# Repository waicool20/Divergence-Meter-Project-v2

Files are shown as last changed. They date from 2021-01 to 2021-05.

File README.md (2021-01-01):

# Divergence Meter Project v2

This is the second iteration of the [Divergence Meter Project](https://github.com/waicool20/Divergence-Meter-Project) and another personal learning project, this time learning how to integrate Li-Ion batteries into a project, new electrical converter topologies, Rust Programming Language and IoT.

Hardware is mostly finalized and most of the work left to do is actually programming the thing to work like the first program along with IoT capabilities via Android companion app. README will remain brief until I actually finish working on this, stay tuned :)

# Images

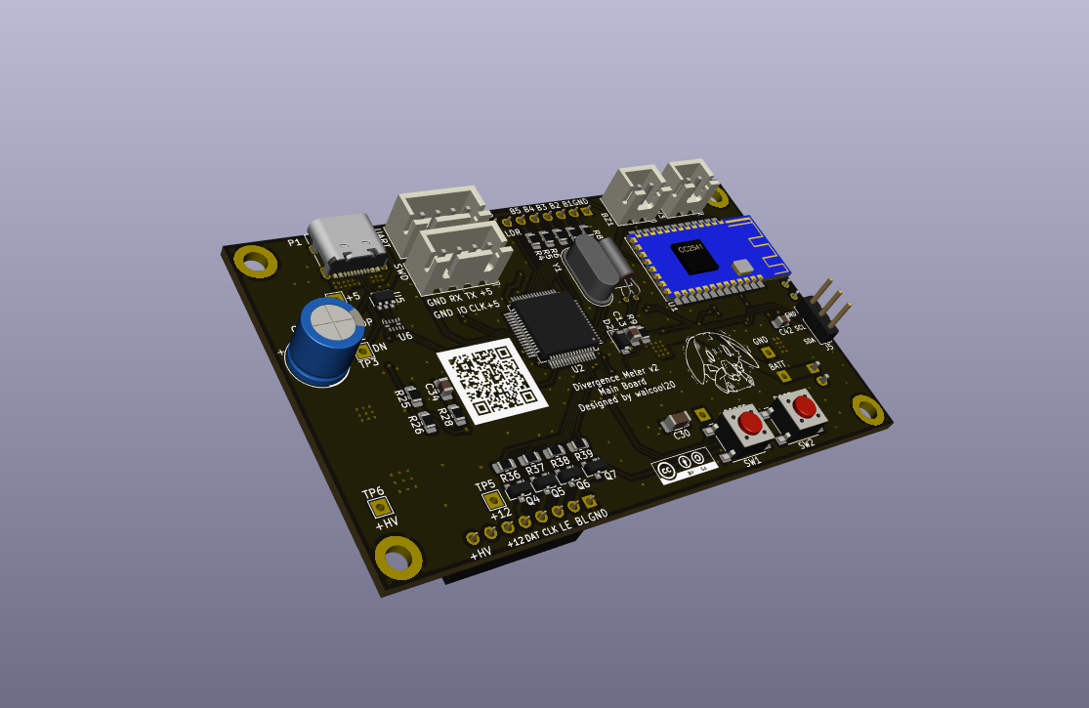
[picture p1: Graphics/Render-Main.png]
Main Board


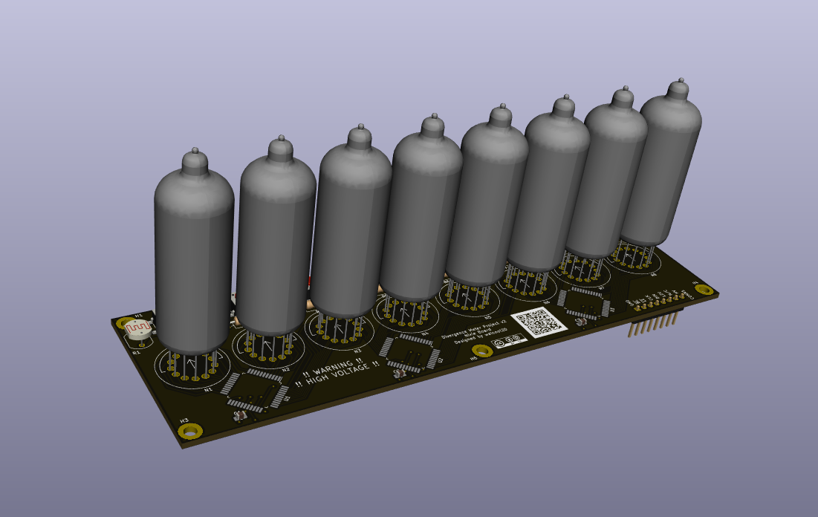
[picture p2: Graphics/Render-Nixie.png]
Nixie Board




# Licenses

Hardware: [Creative Commons Attribution-ShareAlike 4.0 International](https://creativecommons.org/licenses/by-sa/4.0/)  
Software: [GPLv3](https://www.gnu.org/licenses/gpl-3.0.txt)

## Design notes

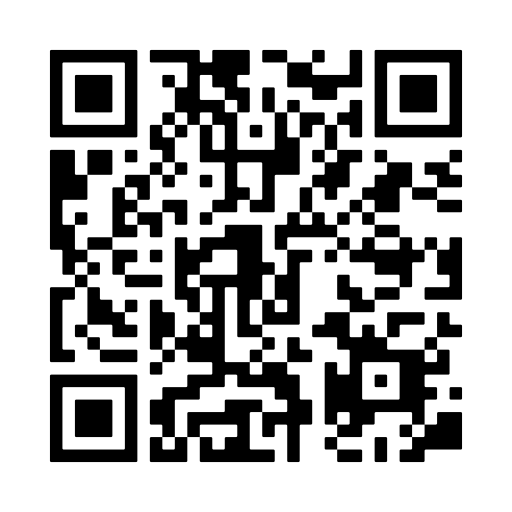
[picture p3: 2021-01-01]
Graphics/GitHub-Link-QR.png

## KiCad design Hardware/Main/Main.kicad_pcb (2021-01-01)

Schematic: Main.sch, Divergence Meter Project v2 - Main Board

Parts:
BZ1: Buzzer; JST_XH_B2B-XH-A_1x02_P2.50mm_Vertical
C1, C2, C3, C4, C5, C6, C7, C8, C13, C14, C15, C16, C17: 0.1u; C_0805_2012Metric_Pad1.18x1.45mm_HandSolder
C9, C10: 22p; C_0805_2012Metric_Pad1.18x1.45mm_HandSolder
C11, C12: 6pf; C_0805_2012Metric_Pad1.18x1.45mm_HandSolder
C43: 2.2u; C_0805_2012Metric_Pad1.18x1.45mm_HandSolder
D1: LL4148; D_MiniMELF
D2: MMSZ4684 3.3v; D_SOD-123
H1, H2, H3, H4: MountingHole_Pad; MountingHole_3.2mm_M3_ISO7380_Pad
J1: SWD; JST_XH_B4B-XH-A_1x04_P2.50mm_Vertical
J2: UART; JST_XH_B4B-XH-A_1x04_P2.50mm_Vertical
J3: CONN1; PinSocket_1x08_P2.54mm_Vertical
J4: CONN2; PinSocket_1x08_P2.54mm_Vertical
Q1: Si2300; SOT-23
R1: 1k; R_0805_2012Metric_Pad1.20x1.40mm_HandSolder
R2, R3, R4, R5, R6, R7, R8, R9, R47: 10k; R_0805_2012Metric_Pad1.20x1.40mm_HandSolder
SW1: Reset; SW_SPST_PTS645
SW2: Boot; SW_SPST_PTS645
U1: DX-BT24
U2: STM32F401RCTx; LQFP-64_10x10mm_P0.5mm
Y1: 8MHz; Crystal_HC49-4H_Vertical
Y2: 32.768kHz; Crystal_C38-LF_D3.0mm_L8.0mm_Horizontal

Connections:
+3V0: C6.2, C14.1, C15.1, C16.1, C17.1, J4.8, R2.1, SW2.2, U1.12, U2.13 (VREF+), U2.19 (VDD), U2.32 (VDD), U2.48 (VDD), U2.64 (VDD); also elsewhere on the board
+5V: J1.1, J2.1; also elsewhere on the board
+12V: J3.6; also elsewhere on the board
+BATT: R9.2; also elsewhere on the board
+HV: J3.8; also elsewhere on the board
/Level Shifter/OUT1: J3.5; also elsewhere on the board
/Level Shifter/OUT2: J3.4; also elsewhere on the board
/Level Shifter/OUT3: J3.3; also elsewhere on the board
/Level Shifter/OUT4: J3.2; also elsewhere on the board
AUX_RX: J2.3, U2.43 (PA10)
AUX_TX: J2.2, U2.42 (PA9)
BATT_INT: U2.2 (PC13); also elsewhere on the board
BATT_SCL: U2.61 (PB8); also elsewhere on the board
BATT_SDA: U2.62 (PB9); also elsewhere on the board
BL: U2.59 (PB7); also elsewhere on the board
BT_CONN: U1.17, U2.15 (PA1)
BT_RX: U1.1, U2.17 (PA3)
BT_TX: U1.2, U2.16 (PA2)
BUTTON1: C3.1, R8.1, U2.21 (PA5)
BUTTON2: C4.1, R7.1, U2.22 (PA6)
BUTTON3: C5.1, R6.1, U2.23 (PA7)
BUTTON4: C7.1, R5.1, U2.24 (PC4)
BUTTON5: C8.1, R4.1, U2.25 (PC5)
BUZZER: Q1.1 (G), R47.1, U2.20 (PA4)
Boot: C2.1, R3.1, SW2.1, U2.60 (BOOT0)
CLK: U2.57 (PB5); also elsewhere on the board
DAT: U2.56 (PB4); also elsewhere on the board
GND: C1.2, C2.2, C3.2, C4.2, C5.2, C6.1, C7.2, C8.2, C9.1, C10.1, C11.1, C12.1, C13.2, C14.2, C15.2, C16.2, C17.2, C43.2, D2.2 (A), H1.1, H2.1, H3.1, H4.1, J1.4, J2.4, J3.1, J4.1, Q1.3 (D), R3.2, R47.2, SW1.1, U1.13, U1.14, U1.26, U2.12 (VSSA), U2.18 (VSS), U2.31 (VSS), U2.47 (VSS), U2.63 (VSS); also elsewhere on the board
HV_ENABLE: U2.50 (PA15); also elsewhere on the board
LDR: J4.7, U2.26 (PB0)
LE: U2.58 (PB6); also elsewhere on the board
NRST: C1.1, R2.2, SW1.2, U2.7 (NRST)
unnamed: BZ1.2 (+), D1.2 (A), Q1.2 (S)
unnamed: C9.2, U2.5 (PH0), Y1.2
unnamed: C10.2, U2.6 (PH1), Y1.1
unnamed: C11.2, U2.3 (PC14), Y2.1
unnamed: C12.2, U2.4 (PC15), Y2.2
unnamed: C13.1, D2.1 (K), R9.1, U2.1 (VBAT)
unnamed: C43.1, U2.30 (VCAP1)
unnamed: D1.1 (K), R1.2
unnamed: J4.2, R8.2
unnamed: J4.3, R7.2
unnamed: J4.4, R6.2
unnamed: J4.5, R5.2
unnamed: J4.6, R4.2
SWDCLK: J1.2, U2.49 (PA14)
SWDIO: J1.3, U2.46 (PA13)
USB_DN: U2.44 (PA11); also elsewhere on the board
USB_DP: U2.45 (PA12); also elsewhere on the board
USB_SEL: U2.41 (PA8); also elsewhere on the board
VBUS_DETECT: U2.40 (PC9); also elsewhere on the board
VCC: BZ1.1 (-), R1.1; also elsewhere on the board

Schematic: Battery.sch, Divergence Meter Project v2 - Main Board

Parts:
BT1: 18650 3.7v; JST_XH_S2B-XH-A-1_1x02_P2.50mm_Horizontal
C18, C21, C23, C26: 1u; C_0805_2012Metric_Pad1.18x1.45mm_HandSolder
C19, C22, C25, C40, C41, C42: 0.1u; C_0805_2012Metric_Pad1.18x1.45mm_HandSolder
C20, C24, C29: 10u; C_0805_2012Metric_Pad1.18x1.45mm_HandSolder
C27: 47n; C_0805_2012Metric_Pad1.18x1.45mm_HandSolder
C28: 4.7u; C_0805_2012Metric_Pad1.18x1.45mm_HandSolder
D3: LED; LED_0805_2012Metric_Pad1.15x1.40mm_HandSolder
D6: LL5819; D_MiniMELF
D7: MMSZ4684 3.3v; D_SOD-123
J5: I2C; PinHeader_1x03_P2.54mm_Vertical
JP1: CE; SolderJumper-2_P1.3mm_Open_TrianglePad1.0x1.5mm
L1: 4.7u; CD54
P1: USB_C_Plug_USB2.0; USB_C_Receptacle_XKB_U262-16XN-4BVC11
R10, R13, R17, R18, R19, R20, R23, R24: 10k; R_0805_2012Metric_Pad1.20x1.40mm_HandSolder
R11: 1.8M; R_0805_2012Metric_Pad1.20x1.40mm_HandSolder
R12: 18.2k; R_0805_2012Metric_Pad1.20x1.40mm_HandSolder
R14, R15: 5.1k; R_0805_2012Metric_Pad1.20x1.40mm_HandSolder
R16: 0.01; R_2512_6332Metric_Pad1.40x3.35mm_HandSolder
R21: 140; R_0805_2012Metric_Pad1.20x1.40mm_HandSolder
R22, R49: 1k; R_0805_2012Metric_Pad1.20x1.40mm_HandSolder
R44, R45: 100; R_0805_2012Metric_Pad1.20x1.40mm_HandSolder
R46, R48: 100k; R_0805_2012Metric_Pad1.20x1.40mm_HandSolder
SW3: PWR; JST_XH_B2B-XH-A_1x02_P2.50mm_Vertical
TH1: 103AT-2; R_Axial_DIN0204_L3.6mm_D1.6mm_P2.54mm_Vertical
TP1: TP_5V; TestPoint_THTPad_2.0x2.0mm_Drill1.0mm
TP2: DP; TestPoint_THTPad_2.0x2.0mm_Drill1.0mm
TP3: DN; TestPoint_THTPad_2.0x2.0mm_Drill1.0mm
TP4: TP_BATT; TestPoint_THTPad_2.0x2.0mm_Drill1.0mm
TP7: TP_VCC; TestPoint_THTPad_2.0x2.0mm_Drill1.0mm
U3: ME6211C30M5; SOT-23-5
U4: BQ27510-G3; Texas_S-PDSO-N12
U5: STF202-22T1G; TSOP-6_1.65x3.05mm_P0.95mm
U6: TS3USB221A; Texas_R-PUQFN-N10
U7: BQ24295; VQFN-24-1EP_4x4mm_P0.5mm_EP2.45x2.45mm_ThermalVias

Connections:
+3V0: C21.1, R10.1, R13.1, R19.2, U3.5, U5.1, U6.10 (VCC); also elsewhere on the board
+5V: C19.2, C20.2, C26.1, D6.2 (A), P1.A4 (VBUS), P1.A9 (VBUS), P1.B4 (VBUS), P1.B9 (VBUS), R46.1, TP1.1, U7.1 (VBUS), U7.24 (VBUS); also elsewhere on the board
+BATT: BT1.1 (+), C23.1, C24.2, TP4.1, U4.3 (REGIN), U4.4 (BAT), U7.13 (BAT), U7.14 (BAT); also elsewhere on the board
BATT_GPOUT: JP1.1 (A), R18.2, U4.12 (GPOUT), U7.9 (~CE)
BATT_INT: R19.1, U7.7 (INT); also elsewhere on the board
BATT_SCL: J5.2, R10.2, U4.11 (SCL), U7.5 (SCL); also elsewhere on the board
BATT_SDA: J5.3, R13.2, U4.10 (SDA), U7.6 (SDA); also elsewhere on the board
CHARGE_DN: U6.2 (1D-), U7.3 (D-)
CHARGE_DP: U6.1 (1D+), U7.2 (D+)
GND: C18.2, C19.1, C20.1, C21.2, C22.2, C23.2, C24.1, C25.2, C26.2, C28.2, C29.1, C40.2, C41.2, D7.2 (A), J5.1, JP1.2 (B), P1.A1 (GND), P1.A12 (GND), P1.B1 (GND), P1.B12 (GND), P1.S1 (SHIELD), R14.2, R15.2, R16.2, R17.1, R20.1, R21.1, R24.2, R45.1, R48.1, TH1.2, U3.2, U4.6 (VSS), U4.13 (PAD), U5.6, U6.5 (GND), U6.6 (~OE), U7.17 (PGND), U7.18 (PGND), U7.25 (PAD); also elsewhere on the board
unnamed: BT1.2 (-), R16.1, R44.1
unnamed: C18.1, R11.1, U4.2 (REG25), U4.5 (VCC)
unnamed: C22.1, R11.2, R12.1, U4.1 (BI/TOUT)
unnamed: C25.1, R49.1, U4.9 (TS)
unnamed: C27.1, U7.21 (BTST)
unnamed: C27.2, L1.1, U7.19 (SW), U7.20 (SW)
unnamed: C28.1, R23.1, U7.22 (REGN)
unnamed: C40.1, C42.2, R45.2, U4.8 (SRN)
unnamed: C41.1, C42.1, R44.2, U4.7 (SRP)
unnamed: D3.1 (K), R22.1
unnamed: D6.1 (K), U3.1, U3.3
unnamed: P1.A5 (CC1), R15.1
unnamed: P1.A6 (D+), P1.B6 (D+), TP2.1, U5.3
unnamed: P1.A7 (D-), P1.B7 (D-), TP3.1, U5.2
unnamed: P1.B5 (CC2), R14.1
unnamed: R12.2, R49.2, TH1.1
unnamed: R20.2, U7.8 (OTG)
unnamed: R21.2, U7.10 (ILIM)
unnamed: R22.2, U7.4 (STAT)
unnamed: R23.2, R24.1, U7.11 (TS)
unnamed: U5.4, U6.8 (D+)
unnamed: U5.5, U6.7 (D-)
USB_DN: U6.4 (2D-); also elsewhere on the board
USB_DP: U6.3 (2D+); also elsewhere on the board
USB_SEL: R17.2, U6.9 (S); also elsewhere on the board
VBUS_DETECT: D7.1 (K), R46.2, R48.2; also elsewhere on the board
VCC: SW3.2 (B), TP7.1; also elsewhere on the board
VSYS: C29.2, D3.2 (A), L1.2, R18.1, SW3.1 (A), U7.15 (SYS), U7.16 (SYS)

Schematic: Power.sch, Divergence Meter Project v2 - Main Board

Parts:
C30, C32, C33: 22u; C_1206_3216Metric_Pad1.33x1.80mm_HandSolder
C31, C34, C37: 0.1u; C_0805_2012Metric_Pad1.18x1.45mm_HandSolder
C35: 470u; CP_Radial_D8.0mm_P3.50mm
C36, C39: 1u; C_0805_2012Metric_Pad1.18x1.45mm_HandSolder
C38: 2.2u 250v; C_1210_3225Metric_Pad1.33x2.70mm_HandSolder
D4: SS34; D_SMA-SMB_Universal_Handsoldering
D5: MURS240; D_SMB_Handsoldering
L2: 4.7u; CD54
Q2: Si2300; SOT-23
Q3: SUD70090E-GE3; TO-252-2
R25, R26, R29, R30: 100k; R_0805_2012Metric_Pad1.20x1.40mm_HandSolder
R27, R32: 10k; R_0805_2012Metric_Pad1.20x1.40mm_HandSolder
R28: 4.7k; R_0805_2012Metric_Pad1.20x1.40mm_HandSolder
R31: 200k; R_0805_2012Metric_Pad1.20x1.40mm_HandSolder
R33: 0.01; R_2512_6332Metric_Pad1.40x3.35mm_HandSolder
R34: 15k; R_0805_2012Metric_Pad1.20x1.40mm_HandSolder
R35: 2M; R_0805_2012Metric_Pad1.20x1.40mm_HandSolder
T1: TTRN-0530H
TP5: TP_12V; TestPoint_THTPad_2.0x2.0mm_Drill1.0mm
TP6: TP_HV; TestPoint_THTPad_2.0x2.0mm_Drill1.0mm
TP8: TP_GND; TestPoint_THTPad_2.0x2.0mm_Drill1.0mm
U8: LM3481; VSSOP-10_3x3mm_P0.5mm
U9: SX1308; TSOT-23-6
U10: ME6211C30M5; SOT-23-5

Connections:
+3V0: C39.1, U10.5; also elsewhere on the board
+12V: C33.1, D4.1 (K), R31.1, TP5.1; also elsewhere on the board
+HV: C38.1, D5.1 (K), R35.1, TP6.1; also elsewhere on the board
GND: C30.2, C31.2, C32.2, C33.2, C34.2, C35.2, C36.2, C37.2, C38.2, C39.2, Q2.2 (S), R25.2, R27.2, R32.2, R33.2, R34.2, T1.5, TP8.1, U8.5 (AGND), U8.7 (PGND), U9.2, U10.2; also elsewhere on the board
HV_ENABLE: Q2.1 (G), R27.1; also elsewhere on the board
unnamed: C31.1, U8.9 (VCC)
unnamed: C34.1, R28.1
unnamed: C37.1, Q3.3 (S), R33.1, U8.1 (Isen)
unnamed: D4.2 (A), L2.2, U9.1
unnamed: D5.2 (A), T1.3
unnamed: Q2.3 (D), R29.2, R30.1
unnamed: Q3.1 (G), U8.8 (DR)
unnamed: Q3.2 (D), T1.1
unnamed: R25.1, R26.2, U8.2 (UVLO)
unnamed: R28.2, U8.3 (COMP)
unnamed: R29.1, U8.6 (FA/SYNC/SD)
unnamed: R31.2, R32.1, U9.3
unnamed: R34.1, R35.2, U8.4 (FB)
VCC: C30.1, C32.1, C35.1, C36.1, L2.1, R26.1, R30.2, T1.2, U8.10 (Vin), U9.4, U9.5, U10.1, U10.3; also elsewhere on the board

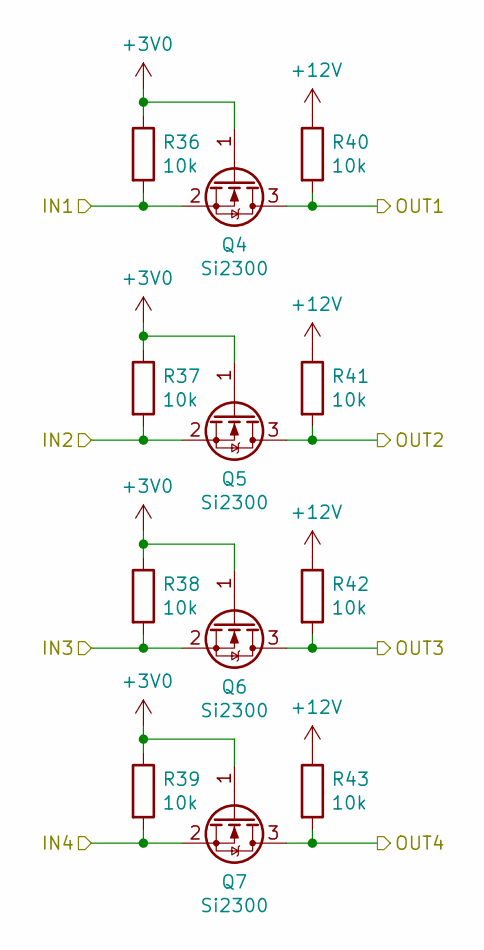
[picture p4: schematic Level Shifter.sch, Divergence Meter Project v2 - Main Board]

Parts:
Q4, Q5, Q6, Q7: Si2300; SOT-23
R36, R37, R38, R39, R40, R41, R42, R43: 10k; R_0805_2012Metric_Pad1.20x1.40mm_HandSolder

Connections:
+3V0: Q4.1 (G), Q5.1 (G), Q6.1 (G), Q7.1 (G), R36.1, R37.1, R38.1, R39.1; also elsewhere on the board
+12V: R40.1, R41.1, R42.1, R43.1; also elsewhere on the board
/Level Shifter/OUT1: Q4.3 (D), R40.2; also elsewhere on the board
/Level Shifter/OUT2: Q5.3 (D), R41.2; also elsewhere on the board
/Level Shifter/OUT3: Q6.3 (D), R42.2; also elsewhere on the board
/Level Shifter/OUT4: Q7.3 (D), R43.2; also elsewhere on the board
BL: Q7.2 (S), R39.2; also elsewhere on the board
CLK: Q5.2 (S), R37.2; also elsewhere on the board
DAT: Q4.2 (S), R36.2; also elsewhere on the board
LE: Q6.2 (S), R38.2; also elsewhere on the board

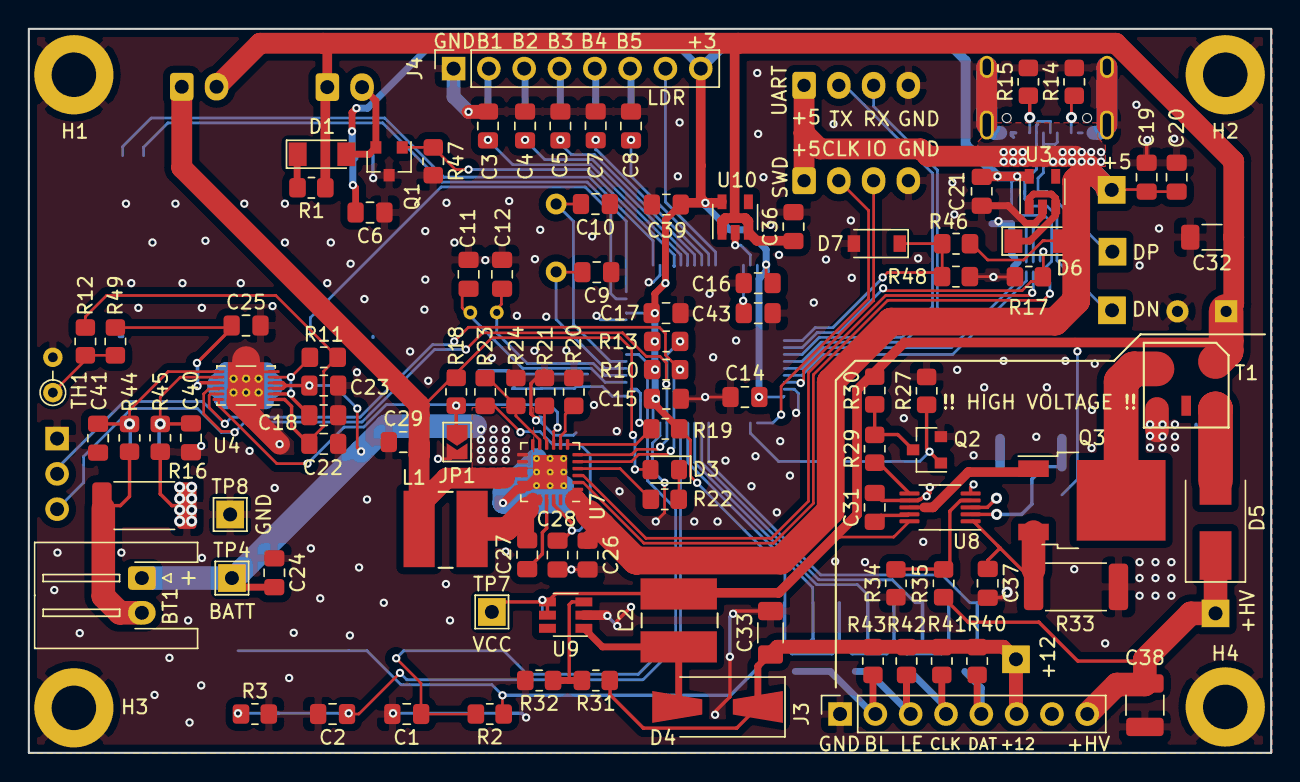
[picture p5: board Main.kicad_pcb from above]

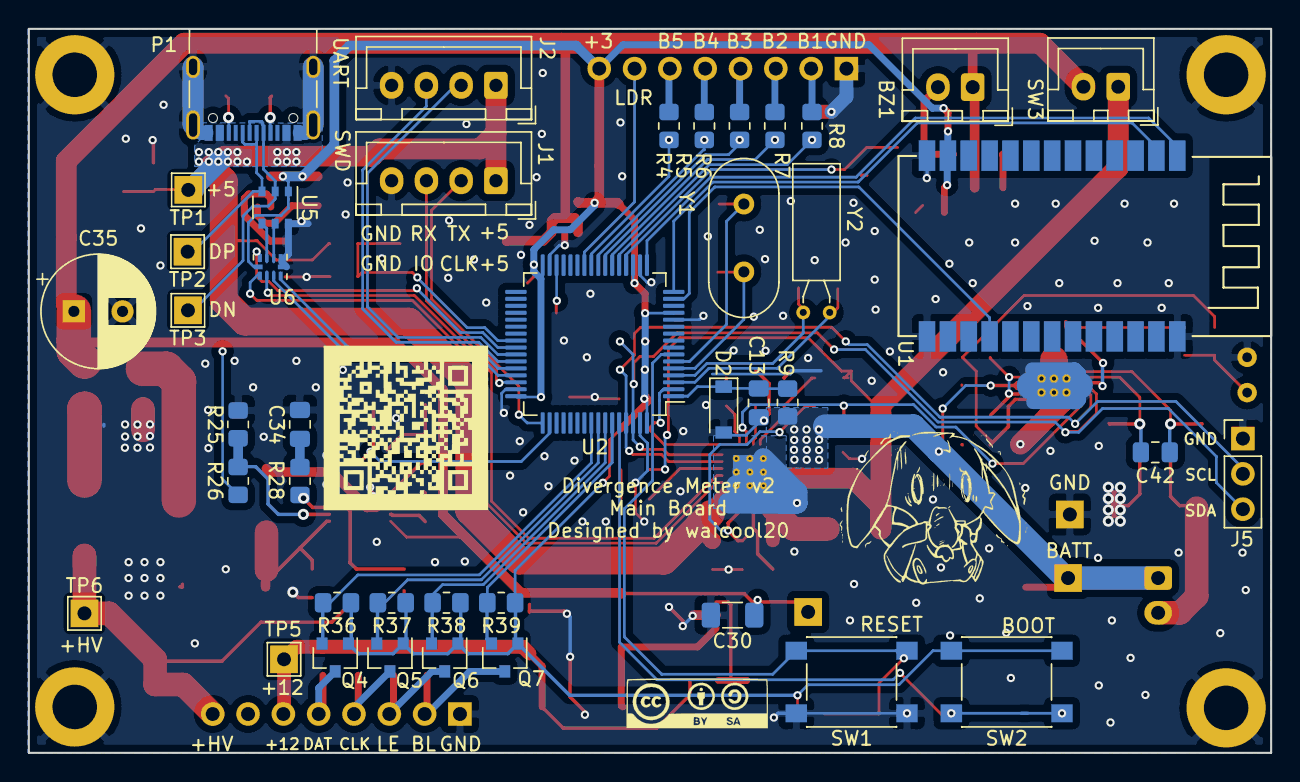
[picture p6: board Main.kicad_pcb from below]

Board: 2 copper layers, 89.3 x 52.1 mm, 146 parts (42 on the bottom side), 91 nets.

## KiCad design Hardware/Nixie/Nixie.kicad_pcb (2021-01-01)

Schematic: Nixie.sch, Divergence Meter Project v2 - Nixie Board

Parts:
C1, C2, C3: 0.1u; C_0805_2012Metric_Pad1.15x1.40mm_HandSolder
H1, H2, H3, H4, H5, H6: MountingHole_Pad; MountingHole_3.2mm_M3_ISO7380_Pad
J1: CONN1; PinHeader_1x08_P2.54mm_Vertical
J2: CONN2; PinHeader_1x08_P2.54mm_Vertical
N1, N2, N3, N4, N5, N6, N7, N8: IN-14
R1: LDR 5516 ( 5-10k ); R_LDR_7x6mm_P5.1mm_Vertical
R2: 100k; R_0805_2012Metric_Pad1.15x1.40mm_HandSolder
R3, R4, R5, R6, R7, R8, R9, R10: 22k; R_Axial_DIN0207_L6.3mm_D2.5mm_P10.16mm_Horizontal
R11, R12, R13, R14, R15: 10k; R_0805_2012Metric_Pad1.15x1.40mm_HandSolder
RV1, RV2, RV3, RV4, RV5, RV6, RV7, RV8: 50k; 3362P
SW1: BUTTON1; SW_SPST_PTS645
SW2: BUTTON2; SW_SPST_PTS645
SW3: BUTTON3; SW_SPST_PTS645
SW4: BUTTON4; SW_SPST_PTS645
SW5: BUTTON5; SW_SPST_PTS645
U1, U2, U3: HV5622-PG; MQFP-44_10x10mm_P0.8mm

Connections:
+3V0: J2.8, R1.1, SW1.2, SW2.2, SW3.2, SW4.2, SW5.2
+12V: C1.1, C2.1, C3.1, J1.6, U1.27, U1.30, U2.27, U2.30, U3.27, U3.30
+HV: J1.8, R3.1, R4.1, R5.1, R6.1, R7.1, R8.1, R9.1, R10.1
BUTTON1: J2.2, R15.1, SW1.1
BUTTON2: J2.3, R14.1, SW2.1
BUTTON3: J2.4, R13.1, SW3.1
BUTTON4: J2.5, R12.1, SW4.1
BUTTON5: J2.6, R11.1, SW5.1
GND: C1.2, C2.2, C3.2, H1.1, H2.1, H3.1, H4.1, H5.1, H6.1, J1.1, J2.1, R2.2, R11.2, R12.2, R13.2, R14.2, R15.2, U1.29, U2.29, U3.29
unnamed: J1.2, U1.33, U2.33, U3.33
unnamed: J1.3, U1.31, U2.31, U3.31
unnamed: J1.4, U1.28, U2.28, U3.28
unnamed: J1.5, U1.32
unnamed: J2.7, R1.2, R2.1
unnamed: N1.1 (A), RV1.2
unnamed: N1.2 (LDP), U1.22
unnamed: N1.3 (1), U1.21
unnamed: N1.4 (2), U1.20
unnamed: N1.5 (3), U1.19
unnamed: N1.6 (4), U1.18
unnamed: N1.7 (5), U1.17
unnamed: N1.8 (6), U1.16
unnamed: N1.9 (7), U1.15
unnamed: N1.10 (8), U1.14
unnamed: N1.11 (9), U1.13
unnamed: N1.12 (0), U1.12
unnamed: N1.13 (RDP), U1.11
unnamed: N2.1 (A), RV2.2
unnamed: N2.2 (LDP), U1.10
unnamed: N2.3 (1), U1.9
unnamed: N2.4 (2), U1.8
unnamed: N2.5 (3), U1.7
unnamed: N2.6 (4), U1.6
unnamed: N2.7 (5), U1.5
unnamed: N2.8 (6), U1.4
unnamed: N2.9 (7), U1.3
unnamed: N2.10 (8), U1.2
unnamed: N2.11 (9), U1.1
unnamed: N2.12 (0), U1.44
unnamed: N2.13 (RDP), U1.43
unnamed: N3.1 (A), RV3.2
unnamed: N3.2 (LDP), U1.42
unnamed: N3.3 (1), U1.41
unnamed: N3.4 (2), U1.40
unnamed: N3.5 (3), U1.39
unnamed: N3.6 (4), U1.38
unnamed: N3.7 (5), U1.37
unnamed: N3.8 (6), U1.36
unnamed: N3.9 (7), U1.35
unnamed: N3.10 (8), U2.22
unnamed: N3.11 (9), U2.21
unnamed: N3.12 (0), U2.20
unnamed: N3.13 (RDP), U2.19
unnamed: N4.1 (A), RV4.2
unnamed: N4.2 (LDP), U2.18
unnamed: N4.3 (1), U2.17
unnamed: N4.4 (2), U2.16
unnamed: N4.5 (3), U2.15
unnamed: N4.6 (4), U2.14
unnamed: N4.7 (5), U2.13
unnamed: N4.8 (6), U2.12
unnamed: N4.9 (7), U2.11
unnamed: N4.10 (8), U2.10
unnamed: N4.11 (9), U2.9
unnamed: N4.12 (0), U2.8
unnamed: N4.13 (RDP), U2.7
unnamed: N5.1 (A), RV5.2
unnamed: N5.2 (LDP), U2.6
unnamed: N5.3 (1), U2.5
unnamed: N5.4 (2), U2.4
unnamed: N5.5 (3), U2.3
unnamed: N5.6 (4), U2.2
unnamed: N5.7 (5), U2.1
unnamed: N5.8 (6), U2.44
unnamed: N5.9 (7), U2.43
unnamed: N5.10 (8), U2.42
unnamed: N5.11 (9), U2.41
unnamed: N5.12 (0), U2.40
unnamed: N5.13 (RDP), U2.39
unnamed: N6.1 (A), RV6.2
unnamed: N6.2 (LDP), U2.38
unnamed: N6.3 (1), U2.37
unnamed: N6.4 (2), U2.36
unnamed: N6.5 (3), U2.35
unnamed: N6.6 (4), U3.22
unnamed: N6.7 (5), U3.21
unnamed: N6.8 (6), U3.20
unnamed: N6.9 (7), U3.19
unnamed: N6.10 (8), U3.18
unnamed: N6.11 (9), U3.17
unnamed: N6.12 (0), U3.16
unnamed: N6.13 (RDP), U3.15
unnamed: N7.1 (A), RV7.2
unnamed: N7.2 (LDP), U3.14
unnamed: N7.3 (1), U3.13
unnamed: N7.4 (2), U3.12
unnamed: N7.5 (3), U3.11
unnamed: N7.6 (4), U3.10
unnamed: N7.7 (5), U3.9
unnamed: N7.8 (6), U3.8
unnamed: N7.9 (7), U3.7
unnamed: N7.10 (8), U3.6
unnamed: N7.11 (9), U3.5
unnamed: N7.12 (0), U3.4
unnamed: N7.13 (RDP), U3.3
unnamed: N8.1 (A), RV8.2
unnamed: N8.2 (LDP), U3.2
unnamed: N8.3 (1), U3.1
unnamed: N8.4 (2), U3.44
unnamed: N8.5 (3), U3.43
unnamed: N8.6 (4), U3.42
unnamed: N8.7 (5), U3.41
unnamed: N8.8 (6), U3.40
unnamed: N8.9 (7), U3.39
unnamed: N8.10 (8), U3.38
unnamed: N8.11 (9), U3.37
unnamed: N8.12 (0), U3.36
unnamed: N8.13 (RDP), U3.35
unnamed: R3.2, RV1.1
unnamed: R4.2, RV2.1
unnamed: R5.2, RV3.1
unnamed: R6.2, RV4.1
unnamed: R7.2, RV5.1
unnamed: R8.2, RV6.1
unnamed: R9.2, RV7.1
unnamed: R10.2, RV8.1
unnamed: U1.23, U2.32
unnamed: U2.23, U3.32

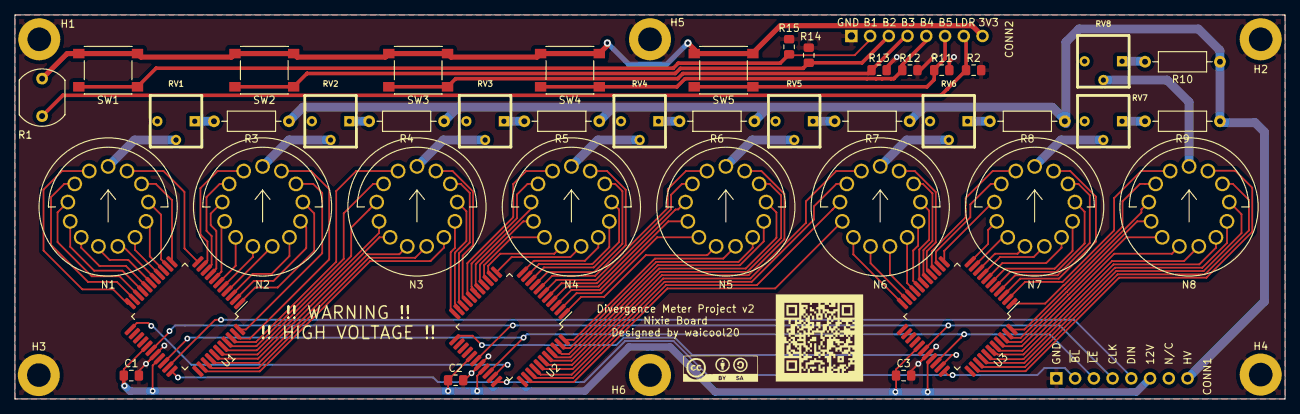
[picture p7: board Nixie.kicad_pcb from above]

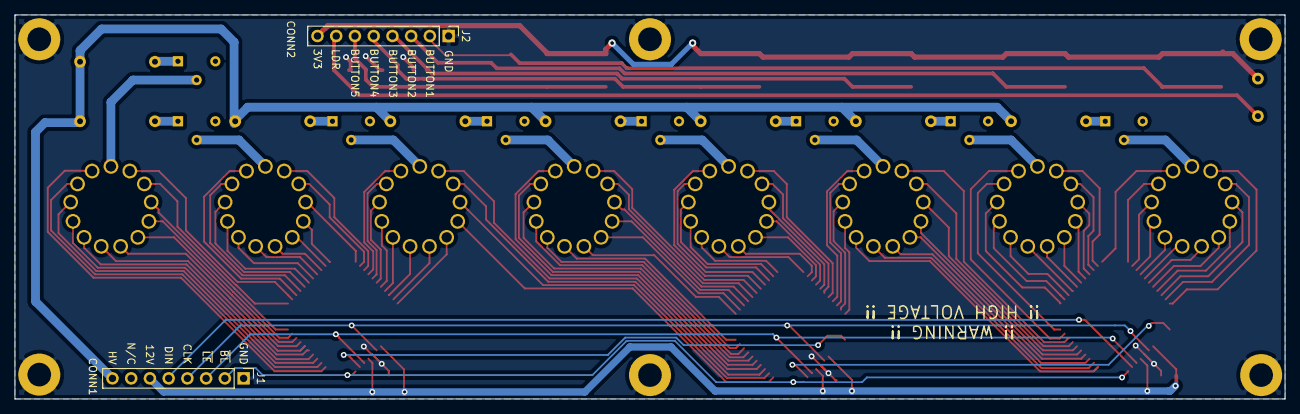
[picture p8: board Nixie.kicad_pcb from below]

Board: 2 copper layers, 172.2 x 52.1 mm, 50 parts (2 on the bottom side), 128 nets.

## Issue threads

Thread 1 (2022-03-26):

transformer

mcer12, 2022-03-26:
Hi, great project! I wanted to make one but the BOM is kinda vague. The most crucial part is the transformer, you only provide type but not what particular model (properties) is needed. Could you elaborate on that?

waicool20, 2022-03-27:
I used the TTRN-0530H-044-T, 11:1 turn ratio, [datasheets should be here](https://www.tokyocoil.com/wp-content/themes/tokyo_coil/pdf/ttrn/TTRN-0530H.pdf) Particular model (044-T part) shouldn't really matter I believe IIRC

Just a note that this project is in a incomplete state, as shown by the lack of progress on the software side of things. As it is, it only displays the current time stored in the RTC with no way to set or unset settings etc.

For now the project will remain in an indefinite hiatus for personal reasons

mcer12, 2022-03-27:
@waicool20 thank you for the reply, I was in a process of ordering components so you stopped me just in time :D I'm worried about different properties - inductance, turns ratio of different models - which I expect would need adjustments of the design which I don't have the tools to properly test. The particular model TTRN-0530H-044-T doesn't seem to be available anywhere except taobao which is too foreign for me :(
Since the project is on ice, maybe I can use the booster design alone, which is super simple and elegant by the way! I've seen this project which uses same switcher but different transformer and slightly different components:
https://www.pcbway.com/project/shareproject/LM3481_high_efficiency_transformer_glow_tube_booster_module.html
but there's very little information about it, maximum current delivery for example.

waicool20, 2022-03-27:
I've not done a lot of testing on current capabilities but it is able to power the 8 tubes at max brightness down to about [3.5V](http://3.5v/) on the [4.2V](http://4.2v/) 10000 mAh li ion cells for a whole day, I havnt figured out how to extract the remaining [0.3V](http://0.3v/) or so on the discharge curve yet tho.

The project you linked has basically the same design which I kind of expected, [TI writes good guidelines on how to use their products](https://www.ti.com/lit/an/snva761a/snva761a.pdf), the only major difference in TIs design is that they use an optocoupler to have full input-output isolation, they also have a lot of extra components to enhance the performance of the circuit, which the project you linked + the one used here mostly omitted due to size driven requirements. Max output current is mostly driven by the selected components, basically if you scale the components up (eg. battery, transformer, mosfet) you can probably increase the current output, but again due to size requirements this is not always the case.

You can get those transformers off of [AliExpress](https://m.aliexpress.com/item/4001298751715.html?gatewayAdapt=Pc2Msite) which should be more accessible, this one is a slightly different model but should work just fine, you can also modify the footprint to fit any other high turn ratio transformer that are available to you.

The specific inductance of the transformers is not as crucial as we're not really powering anything very precise, nixie tubes look elegant but they are pretty crude devices functionally, so power quality is not on the top of the priority list. I wouldn't use the boost circuit for high accuracy applications.

The transformer also heats up quite a bit due to its small size which affects its power delivery capabilities, I think a passive heatsink is needed to achieve better performance.

mcer12, 2022-03-28:
Thank you very much. I will probably merge the two of your designs together, because TTRN-060s-013-T is cheaply available on Ali as I happend to find and it should have higher maximum current so it should run colder. Thank you so much for the clarifications and hope I didn't bother too much with the dumb questions :) I'll reopen the issue in case something else comes up.

Closed 2022-03-28.

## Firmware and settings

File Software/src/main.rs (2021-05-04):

#![no_std]
#![no_main]

#![allow(unused_must_use)]
#![allow(dead_code)]

#[macro_use]
extern crate num_derive;
extern crate panic_halt;
extern crate void;

mod drivers;
mod utils;
mod tasks;
mod hardware;

#[rtic::app(device = stm32f4xx_hal::stm32, peripherals = true, dispatchers = [SDIO, OTG_FS_WKUP])]
mod app {
    use dwt_systick_monotonic::DwtSystick;
    use rtic::rtic_monotonic::Seconds;
    use stm32f4xx_hal::gpio::*;
    use stm32f4xx_hal::gpio::gpioa::*;
    use stm32f4xx_hal::gpio::gpioc::*;
    use stm32f4xx_hal::gpio::gpioc::PC5;
    use stm32f4xx_hal::i2c::I2c;
    use stm32f4xx_hal::prelude::*;
    use stm32f4xx_hal::pwm::tim4;
    use stm32f4xx_hal::rcc::Clocks;
    use stm32f4xx_hal::serial::config::Config;
    use stm32f4xx_hal::serial::Serial;
    use stm32f4xx_hal::stm32;
    use stm32f4xx_hal::stm32::RTC;

    use crate::drivers::battery_charger::*;
    use crate::drivers::battery_gauge::*;
    use crate::drivers::button::Button;
    use crate::drivers::display::*;
    use crate::hardware::*;
    use crate::tasks::*;

    #[resources]
    struct Resources {
        #[lock_free]
        display: HwDisplay,
        clocks: Clocks,
        #[lock_free]
        rtc: RTC,
        #[lock_free]
        buttons: [Button; 5],
        #[lock_free]
        pin_b1: PA5<Input<Floating>>,
        #[lock_free]
        pin_b2: PA6<Input<Floating>>,
        #[lock_free]
        pin_b3: PA7<Input<Floating>>,
        #[lock_free]
        pin_b4: PC4<Input<Floating>>,
        #[lock_free]
        pin_b5: PC5<Input<Floating>>,
        #[lock_free]
        battery_charger: HwBatteryCharger,
        #[lock_free]
        battery_gauge: HwBatteryGauge,
        #[lock_free]
        vbus_detect: PC9<Input<Floating>>,
    }

    #[monotonic(binds = SysTick, default = true)]
    type MyMono = DwtSystick<8_000_000>;

    #[init]
    fn init(cx: init::Context) -> (init::LateResources, init::Monotonics) {
        let mut cp: cortex_m::Peripherals = cx.core;
        let mut dp: stm32::Peripherals = cx.device;
        cp.DWT.enable_cycle_counter();

        // Init RTC
        dp.RCC.apb1enr.modify(|_, w| w.pwren().enabled());
        dp.PWR.cr.modify(|_, w| w.dbp().set_bit());
        if dp.RCC.bdcr.read().lserdy().is_not_ready() {
            dp.RCC.bdcr.modify(|_, w| w.lseon().on());
            while dp.RCC.bdcr.read().lserdy().is_not_ready() {}
        }
        if dp.RCC.bdcr.read().rtcen().is_disabled() {
            dp.RCC.bdcr.modify(|_, w| {
                w.rtcsel().lse();
                w.rtcen().enabled()
            });
        }

        dp.RCC.apb2enr.modify(|_, w| w.syscfgen().enabled());

        let clocks = dp.RCC.constrain().cfgr.use_hse(8.mhz())
            .sysclk(48.mhz())
            .freeze();

        let mut syscfg = &mut dp.SYSCFG.constrain();

        let mut gpiob = dp.GPIOB.split();
        let mut gpioa = dp.GPIOA.split();
        let mut gpioc = dp.GPIOC.split();

        // Init Buttons
        let pin_b1 = gpioa.pa5.into_floating_input();
        let pin_b2 = gpioa.pa6.into_floating_input();
        let pin_b3 = gpioa.pa7.into_floating_input();
        let pin_b4 = gpioc.pc4.into_floating_input();
        let pin_b5 = gpioc.pc5.into_floating_input();

        // Init Display
        let pin_le = gpiob.pb6.into_push_pull_output();
        let pin_dat = gpiob.pb4.into_push_pull_output();
        let pin_clk = gpiob.pb5.into_push_pull_output();
        let pin_en = gpioa.pa15.into_push_pull_output();
        let pin_bl = gpiob.pb7.into_alternate_af2();
        let pwm = tim4(dp.TIM4, pin_bl, clocks, 1.khz());
        let mut display = Display::new(pin_dat, pin_clk, pin_le, pin_en, pwm);

        // Init Bluetooth Serial
        let bt_tx = gpioa.pa2.into_alternate_af7();
        let bt_rx = gpioa.pa3.into_alternate_af7();
        let serial = Serial::usart2(dp.USART2, (bt_tx, bt_rx), Config::default().baudrate(9600.bps()), clocks).unwrap();
        let (mut tx, mut rx) = serial.split();

        // Init Battery I2C
        let batt_scl = gpiob.pb8.into_alternate_af4_open_drain();
        let batt_sda = gpiob.pb9.into_alternate_af4_open_drain();
        let i2c = I2c::new(dp.I2C1, (batt_scl, batt_sda), 400.khz(), clocks);
        let bus: &'static _ = shared_bus::new_cortexm!(HwI2c = i2c).unwrap();
        let mut battery_charger = BatteryCharger::new(bus.acquire_i2c()).unwrap();
        let mut battery_gauge = BatteryGauge::new(bus.acquire_i2c()).unwrap()
            .unseal_full_access(DEFAULT_UNSEAL_KEY, DEFAULT_FULL_ACCESS_KEY).ok().unwrap();

        // Init USB
        let mut usb_sel = gpioa.pa8.into_push_pull_output();

        let mut vbus_detect = gpioc.pc9.into_floating_input();
        vbus_detect.make_interrupt_source(syscfg);
        vbus_detect.enable_interrupt(&mut dp.EXTI);
        vbus_detect.trigger_on_edge(&mut dp.EXTI, Edge::RISING);

        let mono = DwtSystick::new(&mut cp.DCB, cp.DWT, cp.SYST, 8_000_000);

        // Start main
        task_main::spawn().unwrap();
        task_buttons::spawn().unwrap();
        task_charger::spawn().unwrap();

        (init::LateResources {
            display,
            clocks,
            rtc: dp.RTC,
            buttons: [Button::new(); 5],
            pin_b1,
            pin_b2,
            pin_b3,
            pin_b4,
            pin_b5,
            battery_charger,
            battery_gauge,
            vbus_detect,
        }, init::Monotonics(mono))
    }

    extern "Rust" {
        #[task(resources = [display, & clocks, rtc])]
        fn task_main(_cx: task_main::Context);

        #[task(priority = 2, resources = [buttons, & clocks, pin_b1, pin_b2, pin_b3, pin_b4, pin_b5])]
        fn task_buttons(_cx: task_buttons::Context);

        #[task(resources = [& clocks, battery_charger])]
        fn task_charger(_cx: task_charger::Context);

        #[task(binds = EXTI9_5, resources = [& clocks, vbus_detect])]
        fn task_vbus_detect(cx: task_vbus_detect::Context);
    }
}

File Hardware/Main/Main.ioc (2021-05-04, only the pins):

Mcu.UserName=STM32F401RCTx
PA6.GPIO_Label=BUTTON2
PB0.GPIO_Label=LDR
PB6.GPIO_Label=LE
PA15.GPIO_Label=HV_ENABLE
PA12.Signal=USB_OTG_FS_DP
PB6.Signal=GPIO_Output
PC13-ANTI_TAMP.Signal=GPIO_Input
PC4.GPIO_Label=BUTTON4
PA10.GPIO_Label=AUX_RX
PB7.Signal=S_TIM4_CH2
PA8.Signal=GPIO_Output
PB7.GPIO_Label=BL
PB9.Signal=I2C1_SDA
PA6.Signal=GPIO_Input
PA2.GPIO_Label=BT_TX
PA10.Signal=USART1_RX
PA15.Signal=GPIO_Output
PB5.GPIO_Label=CLK
PC5.Signal=GPIO_Input
PA4.GPIO_Label=BUZZER
PB4.Signal=GPIO_Output
PA3.Signal=USART2_RX
PB9.GPIO_Label=BATT_SDA
PC9.GPIO_Label=VBUS_DETECT
PC13-ANTI_TAMP.GPIO_Label=BATT_INT
PA9.GPIO_Label=AUX_TX
PC4.Signal=GPIO_Input
PC14-OSC32_IN.Signal=RCC_OSC32_IN
PA13.Signal=SYS_JTMS-SWDIO
PB8.GPIO_Label=BATT_SCL
PA8.GPIO_Label=USB_SEL
PA9.Signal=USART1_TX
PC15-OSC32_OUT.Signal=RCC_OSC32_OUT
PA1.Signal=GPIO_Input
PA5.Signal=GPIO_Input
PB4.GPIO_Label=DAT
PA1.GPIO_Label=BT_CONN
PA2.Signal=USART2_TX
PA4.Signal=GPIO_Output
PB5.Signal=GPIO_Output
PA7.GPIO_Label=BUTTON3
PA5.GPIO_Label=BUTTON1
PC5.GPIO_Label=BUTTON5
PA11.Signal=USB_OTG_FS_DM
PA14.Signal=SYS_JTCK-SWCLK
PB8.Signal=I2C1_SCL
PC9.Signal=GPIO_Input
PB0.Signal=ADCx_IN8
PA3.GPIO_Label=BT_RX
PA7.Signal=GPIO_Input

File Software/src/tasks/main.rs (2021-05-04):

use stm32f4xx_hal::rcc::Clocks;
use stm32f4xx_hal::stm32::RTC;

use crate::app;
use crate::drivers::display::Digit;
use crate::hardware::*;
use crate::utils::delay::{Delay, DelayMs};

pub fn task_main(cx: app::task_main::Context) {
    let display: &mut HwDisplay = &mut *cx.resources.display;
    let clocks: &Clocks = cx.resources.clocks;
    let rtc: &mut RTC = cx.resources.rtc;

    let mut delay = Delay::new(*clocks);

    if rtc.tr.read().st().bits() == 0 && rtc.tr.read().su().bits() == 0 {
        display.roll(&mut delay, [
            Digit::from(rtc.dr.read().yt().bits()),
            Digit::from(rtc.dr.read().yu().bits()),
            Digit::Off,
            Digit::from(rtc.dr.read().mt().bits() as u8),
            Digit::from(rtc.dr.read().mu().bits()),
            Digit::Off,
            Digit::from(rtc.dr.read().dt().bits()),
            Digit::from(rtc.dr.read().du().bits())
        ]);
        delay.delay_ms(3000u32);
    } else {
        let dot = rtc.tr.read().su().bits() % 2 == 0;
        display.clear();
        display.tubes[0].digit = Digit::from(rtc.tr.read().ht().bits());
        display.tubes[1].digit = Digit::from(rtc.tr.read().hu().bits());
        display.tubes[2].show_ldp = dot;
        display.tubes[2].show_rdp = !dot;
        display.tubes[3].digit = Digit::from(rtc.tr.read().mnt().bits());
        display.tubes[4].digit = Digit::from(rtc.tr.read().mnu().bits());
        display.tubes[5].show_ldp = dot;
        display.tubes[5].show_rdp = !dot;
        display.tubes[6].digit = Digit::from(rtc.tr.read().st().bits());
        display.tubes[7].digit = Digit::from(rtc.tr.read().su().bits());
        display.refresh();
    }

    // Run every second
    app::task_main::spawn_after(rtic::time::duration::Seconds(1u32)).unwrap();
}

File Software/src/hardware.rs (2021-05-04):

use shared_bus::{CortexMMutex, I2cProxy};
use stm32f4xx_hal::gpio::{AF4, AlternateOD, Output, PushPull};
use stm32f4xx_hal::gpio::gpioa::PA15;
use stm32f4xx_hal::gpio::gpiob::{PB4, PB5, PB6, PB8, PB9};
use stm32f4xx_hal::i2c::I2c;
use stm32f4xx_hal::pwm::{C2, PwmChannels};
use stm32f4xx_hal::stm32::{I2C1, TIM4};

use crate::drivers::battery_charger::BatteryCharger;
use crate::drivers::battery_gauge::{BatteryGauge, Unsealed};
use crate::drivers::display::Display;

pub type HwI2c = I2c<I2C1, (PB8<AlternateOD<AF4>>, PB9<AlternateOD<AF4>>)>;
pub type HwDisplay = Display<PB4<Output<PushPull>>, PB5<Output<PushPull>>, PB6<Output<PushPull>>, PA15<Output<PushPull>>, PwmChannels<TIM4, C2>>;

type _I2CBus = I2cProxy<'static, CortexMMutex<HwI2c>>;
pub type HwBatteryCharger = BatteryCharger<_I2CBus>;
pub type HwBatteryGauge = BatteryGauge<Unsealed, _I2CBus>;
